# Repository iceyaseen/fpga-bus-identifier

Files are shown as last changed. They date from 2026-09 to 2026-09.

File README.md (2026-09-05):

# FPGA Communication Checker

A tool for figuring out how an unknown chip talks before you know anything about it. The usual situation: you have a small component with 3 or 4 pins, no datasheet, and no idea which protocol it speaks or what each pin does. Instead of guessing, you hook it up to this board and look at what actually happens on the lines.

## Status

The FPGA side is still in progress.

Working today:
- Edge capture on two probe channels, timestamped and streamed to a Python host over UART at 921600 baud.
- A framed, checksummed, self-resynchronising UART protocol between the FPGA and the host (start/stop/reset/status commands, edge records, ACK/ERROR replies).
- A from-scratch UART tx/rx pair, built and tested on the Tang Nano 9K.
- A 256-entry, block-RAM-backed capture FIFO, with high-water mark reported in the status reply.
- A PySide6 + pyqtgraph host GUI (dark instrument theme): live or offline (loaded from CSV) waveform view with pan/zoom/cursor/two draggable markers, a log-scale/zoomable pulse-width histogram, CSV export, and a "protocol hint" panel that reads the dominant pulse width and reports the closest matching clock/UART baud/1-Wire pulse - timing arithmetic only, not protocol decoding.
- An active I2C master: bidirectional open-drain probe drivers, software-switchable pull-ups, an electrical pre-scan (own pull-up / needs ours / held low / floating, per channel, before any bus traffic), and a 0x08-0x77 address sweep that reports every address that ACKs. Driven from the host's "Scan I2C" button; verified in simulation against a fake I2C slave (exactly one address found, START/STOP/ACK timing checked against spec) and confirmed on real hardware against an MLX90614 at 0x5A.

Not built yet:
- Reading actual data back from a found device (the I2C master currently only does the one-byte address-probe transaction a scan needs).
- Decoders for UART, 1-Wire, and PWM.
- Detection of analog (non-digital) devices - everything so far assumes the thing on the probes is digital.

## Host software

Requires Python 3 plus:
```
pip install PySide6 pyqtgraph pyserial
```
Then run:
```
python3 host/host.py [serial-port]
```
`host/protocol.py` holds the wire-format parser (framing, checksums, resync) and `host/hint.py` the protocol-hint arithmetic; both are plain Python with no GUI dependency, and each has a standalone test script (`host/test_frame_parser.py`, `host/test_hint.py`) that can be run without any hardware attached.

<p align="center">
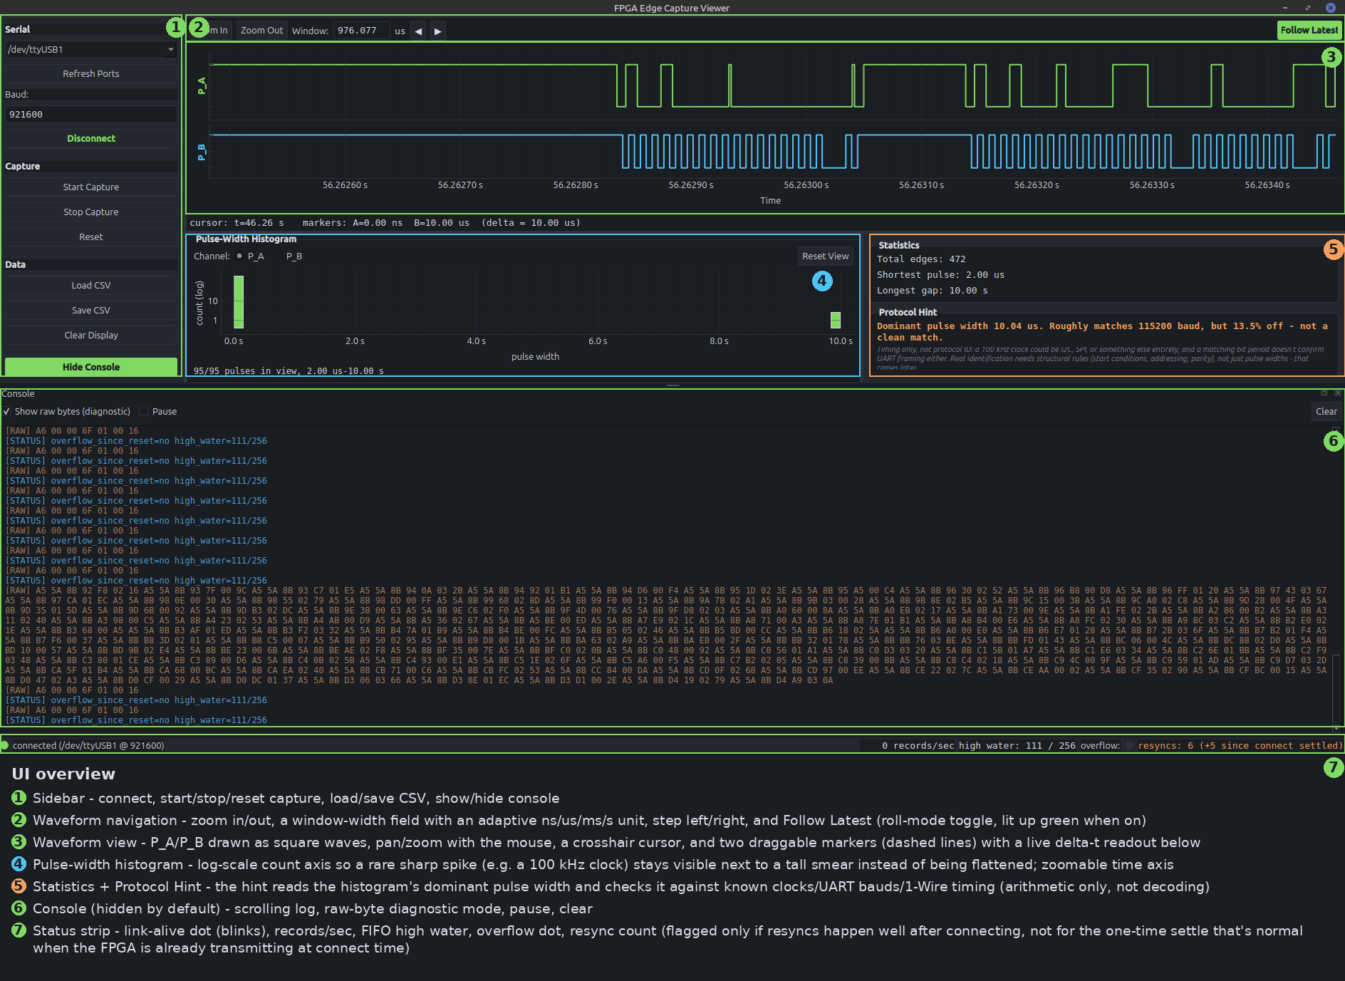
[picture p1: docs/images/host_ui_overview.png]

<br>
<sup>Screenshot of a real capture, probed on P_A/P_B. Numbered callouts below.</sup>
</p>

1. **Sidebar** - connect, start/stop/reset capture, load/save CSV, show/hide the console.
2. **Waveform navigation** - zoom in/out, a window-width field with an adaptive ns/us/ms/s unit, step left/right, and Follow Latest (an oscilloscope-style roll-mode toggle, lit up green when on).
3. **Waveform view** - P_A/P_B drawn as square waves. Pan/zoom with the mouse, a crosshair cursor that follows it, and two draggable markers (dashed lines) with a live delta-t readout below the plot.
4. **Pulse-width histogram** - log-scale count axis, so a rare sharp spike (e.g. a 100 kHz clock) stays visible next to a much taller structureless smear instead of being flattened to nothing; the time axis is independently zoomable to reveal fine structure.
5. **Statistics + Protocol Hint** - live edge/pulse/gap stats, plus a hint that reads the histogram's dominant pulse width and checks it against known clocks, standard UART bauds, and 1-Wire timing. Pure arithmetic, never a claim to have identified a protocol - see the disclaimer printed under it.
6. **Console** (hidden by default) - the scrolling log, a raw-byte diagnostic mode, pause (freezes the view without losing anything), and clear.
7. **Status strip** - a link-alive dot that blinks while connected, live records/sec, FIFO high-water mark, a sticky overflow-since-reset dot, and the frame resync count (flagged only if resyncs happen well after connecting, not for the one-time settle that's normal when the FPGA is already transmitting at connect time).

## The PCB

A shield that sits on top of the Tang Nano 9K. Built and working, not just designed - the photos below are the real board. It has two probe channels and a 4-pin socket for the device under test.
<p align="center">
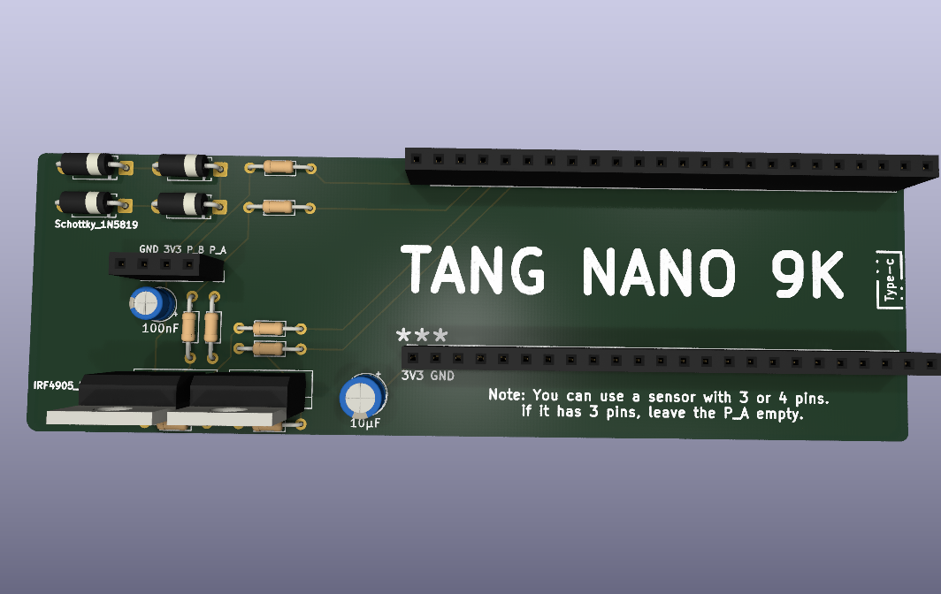
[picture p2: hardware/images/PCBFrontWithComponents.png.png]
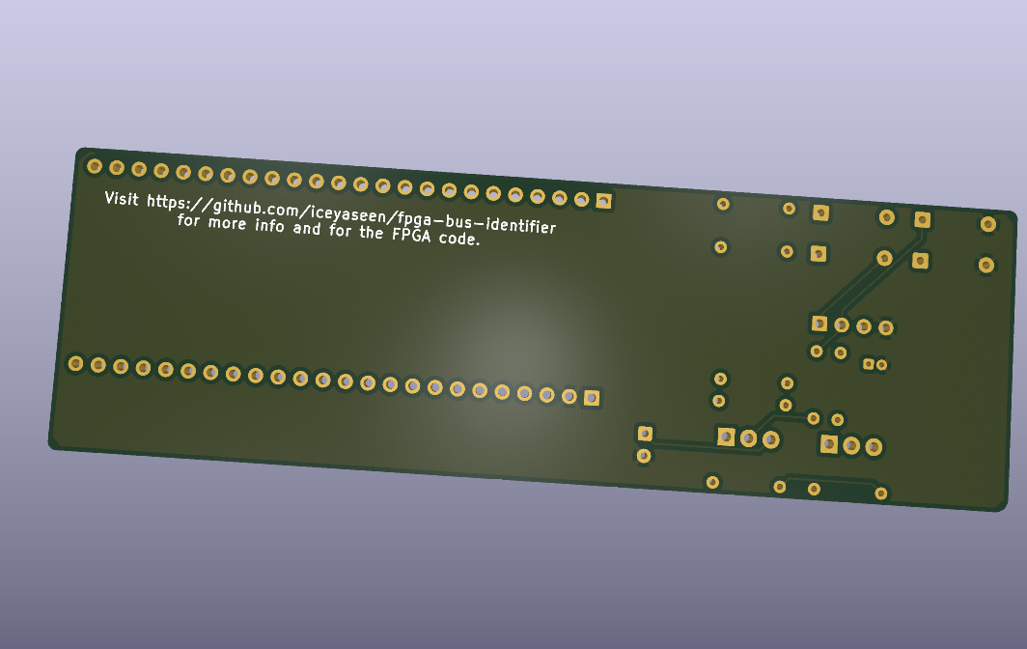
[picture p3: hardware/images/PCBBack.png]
  
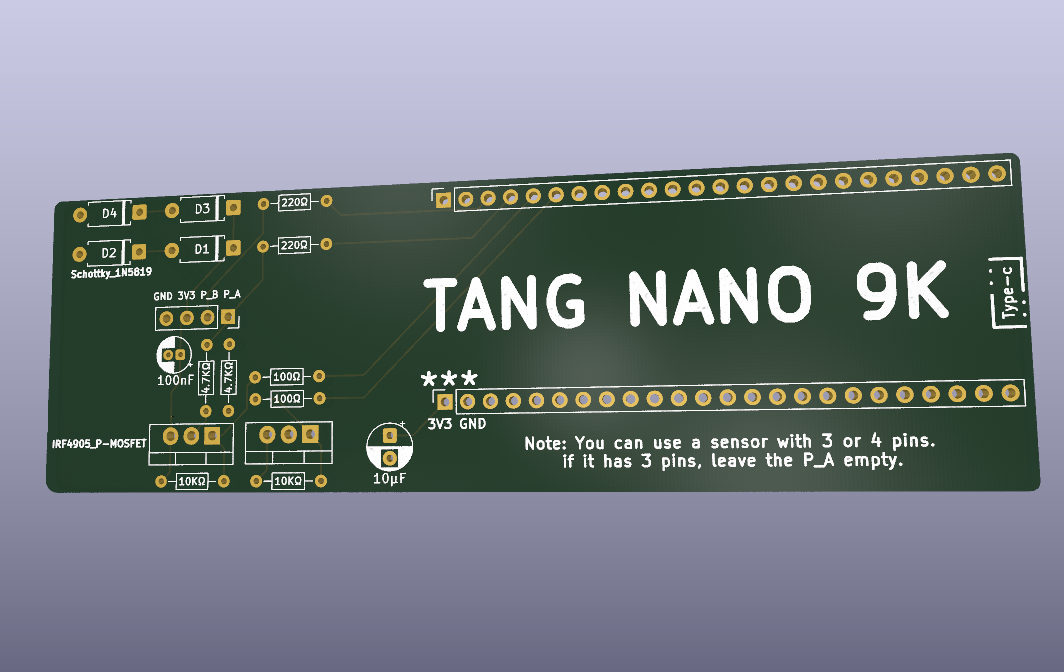
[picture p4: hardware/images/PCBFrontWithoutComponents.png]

<br>
Each part on the probe lines is there for a specific reason:
</p>

- **220 ohm series resistor** on each probe line. The tool is meant to connect to devices whose voltage and drive strength are unknown, so the series resistor limits current if something unexpected is being driven.
- **Schottky clamp diodes (1N5819)** to 3.3V and GND on each probe line, so an over-voltage device can't reach the FPGA pin directly. Schottky specifically, not an ordinary diode: an ordinary diode clamps around 4.0V, which is already too high for this FPGA's inputs.
- **4.7k pull-ups switched by P-channel MOSFETs.** This is the part that needs explaining: to find out whether an unknown device already has its own pull-up, you need to disconnect ours first and see what the line does on its own. A fixed pull-up would make that measurement impossible, so it's switchable instead.
- **10k gate-to-source resistors** on those MOSFETs, so they stay off during the few milliseconds after power-up while the FPGA is still loading its bitstream and its pins are floating.

## Pin assignments

| Tang Nano 9K pin | Signal | Notes |
|---|---|---|
| 54 | `ctrl_b` | Active low. Pulling low turns on channel B's pull-up MOSFET. |
| 55 | `ctrl_a` | Active low. Pulling low turns on channel A's pull-up MOSFET. |
| 56 | `probe_a`  | Probe channel A. |
| 57 | `probe_b`  | Probe channel B. |

Active low because these drive P-channel MOSFETs, which turn on when their gate is pulled low.

## Using it

Plug the unknown device into the 4-pin socket. A 4-pin device fills all four positions. A 3-pin device leaves `probe_a` empty.

## I2C scanning

Click **Scan I2C** in the host app. It runs two steps automatically:

1. **Electrical pre-scan** - before any bus traffic, each channel is classified purely by watching pull-up behaviour: *has its own pull-up* (reads high with ours off), *needs ours* (low/floating with ours off, clean high once ours switches on), *held low* (still low even with our pull-up on - a device driving it, or a short), or *floating* (unstable with no pull-up at all - nothing connected). This tells you whether the device is even I2C-shaped before wasting time on an address sweep.
2. **Address sweep** - START, address + write bit, check for ACK, STOP, for every address 0x08-0x77 (the valid 7-bit range). Every address that ACKs gets reported; an empty result is reported as "No devices found", not left ambiguous.

**Which probe is SDA and which is SCL is not auto-detected** - it's a host-side toggle ("SDA/SCL mapping: Normal (A=SDA, B=SCL) / Swapped (A=SCL, B=SDA)"), simpler and more transparent than guessing. If a scan against a known-good device finds nothing, flip the mapping and scan again. Verified against a real MLX90614 infrared thermometer (address 0x5A) on real hardware.

The scan's own generated I2C traffic is visible in the waveform view too (make sure capture is running - the "Scan I2C" button starts it automatically) - a good way to confirm the master is generating correct signals, not just trusting the reported result.

New host commands, single bytes like the existing ones (no framing needed on that side):

| Command | Effect |
|---|---|
| `A` / `a` | channel A pull-up on / off |
| `B` / `b` | channel B pull-up on / off |
| `N` / `W` | normal / swapped SDA-SCL pin mapping |
| `E` | run the electrical pre-scan |
| `I` | run the address sweep |

`E` and `I` are long-running, so unlike every other command their ACK is deferred until the operation actually finishes, not when the byte arrives - that's what lets the host safely chain pre-scan -> sweep off the pre-scan's own ACK. Two new frame types carry the results: `0xA9 PRESCAN_RESULT` (channel, category) and `0xAA ADDR_HIT` (one address that ACKed) - see `host/protocol.py` for the exact wire format, which follows the same `[MARKER][PAYLOAD][CHECKSUM]` scheme as everything else.

## Screenshots

<p align="center">
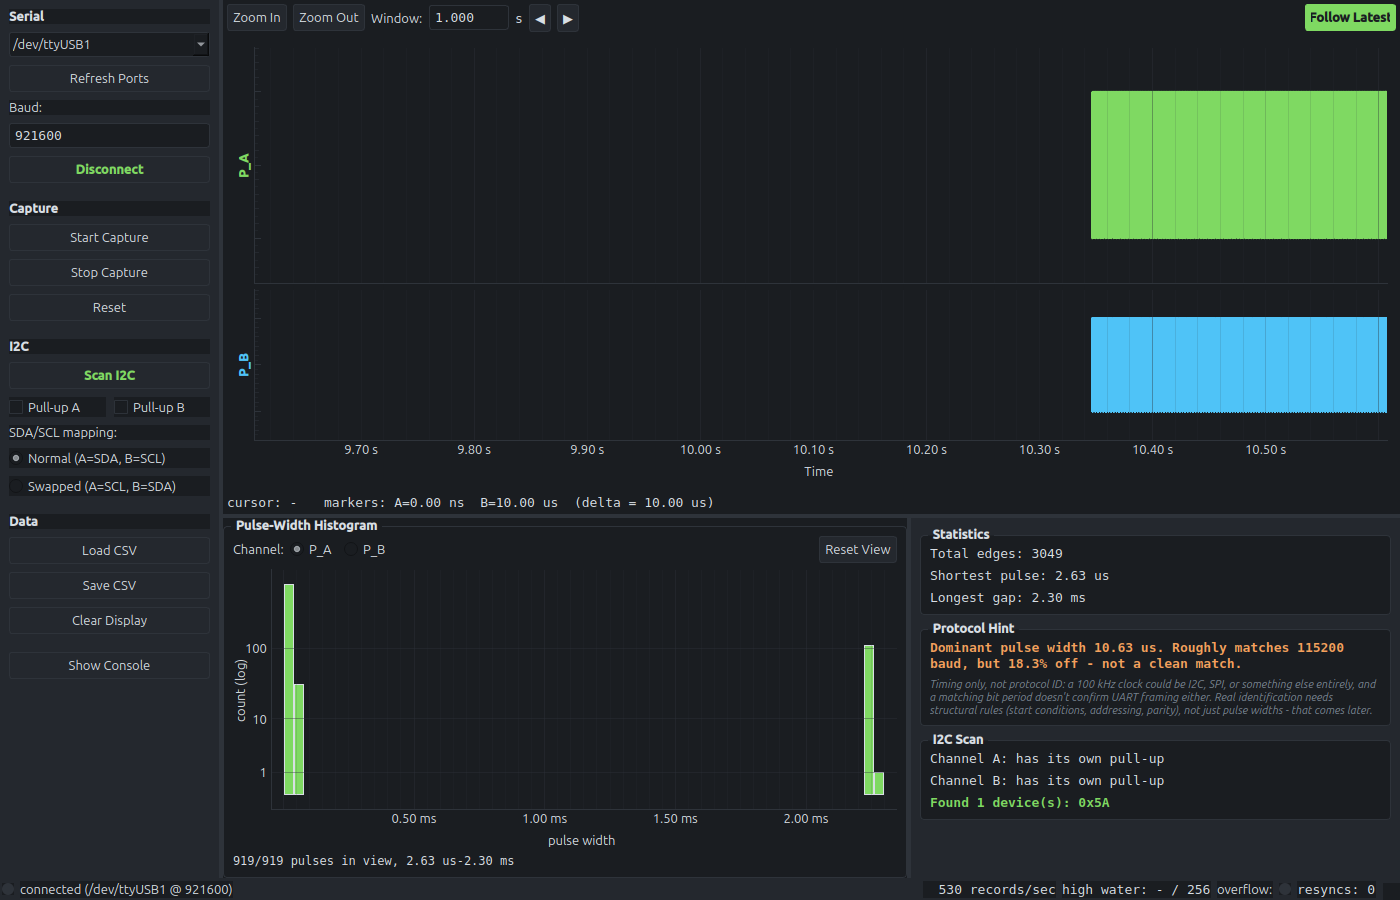
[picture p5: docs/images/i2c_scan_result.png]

<br>
<sup>A real scan: the pre-scan found a pull-up already present on both channels, and the address sweep found one device, at 0x5A - a real MLX90614 infrared thermometer.</sup>
</p>

<p align="center">
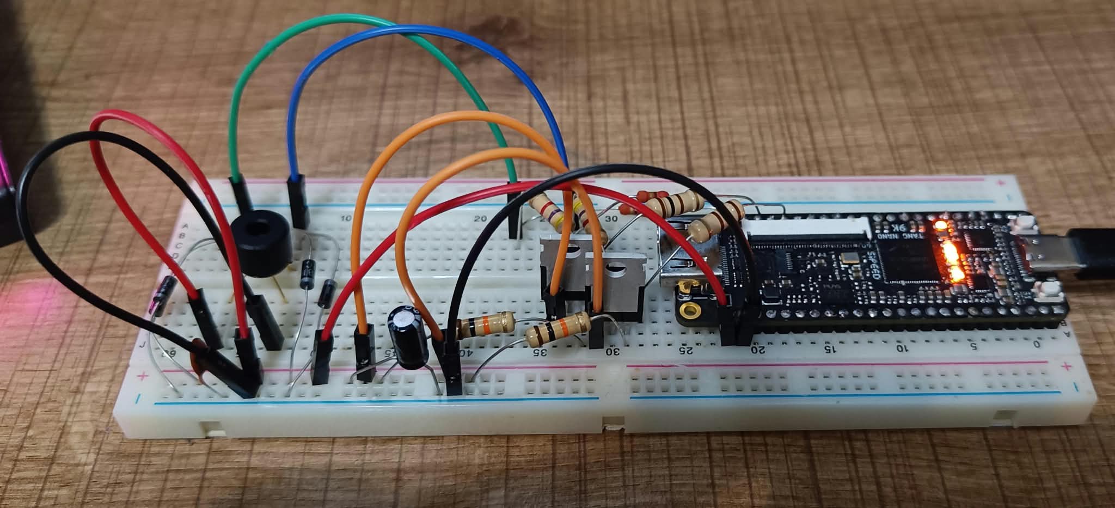
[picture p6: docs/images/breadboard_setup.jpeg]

<br>
<sup>The Tang Nano 9K wired up on a breadboard while testing against a real MLX90614.</sup>
</p>

General decoupling notes for this kind of breadboard setup: keep the 10uF bulk capacitor close to the 3.3V and GND rails it's decoupling, and keep the 100nF ceramic capacitor close to the sensor under test, not back at the FPGA end - it's there to filter noise right at the device, and a long lead defeats the point.

| Signal | Tang Nano 9K pin | Goes to |
|---|---|---|
| `probe_a` | 56 | Sensor SDA or SCL (depends on the SDA/SCL mapping setting) |
| `probe_b` | 57 | Sensor SCL or SDA (the other line) |
| `ctrl_a` | 55 | Channel A pull-up MOSFET gate |
| `ctrl_b` | 54 | Channel B pull-up MOSFET gate |
| 3.3V | - | Sensor VDD |
| GND | - | Sensor GND, common return |

Waveform and pulse-width-histogram screenshots of real captured I2C traffic, plus a contact-bounce histogram for comparison, are still to come - they need the hardware connected and, for the bounce case, a saved capture that doesn't exist yet.

## Known limitations

- Only single-ended protocols are in scope. CAN and RS-485 are differential and need a transceiver, so they're not supported.
- A completely unpowered unknown chip can't be identified from the outside. This tool only works on devices that respond when probed.
- There are two probe channels, so SPI (which needs more lines) isn't reachable yet.
- The protocol hint only measures timing. A 100 kHz clock could be I2C or SPI - the hint says "consistent with", it does not identify the protocol.

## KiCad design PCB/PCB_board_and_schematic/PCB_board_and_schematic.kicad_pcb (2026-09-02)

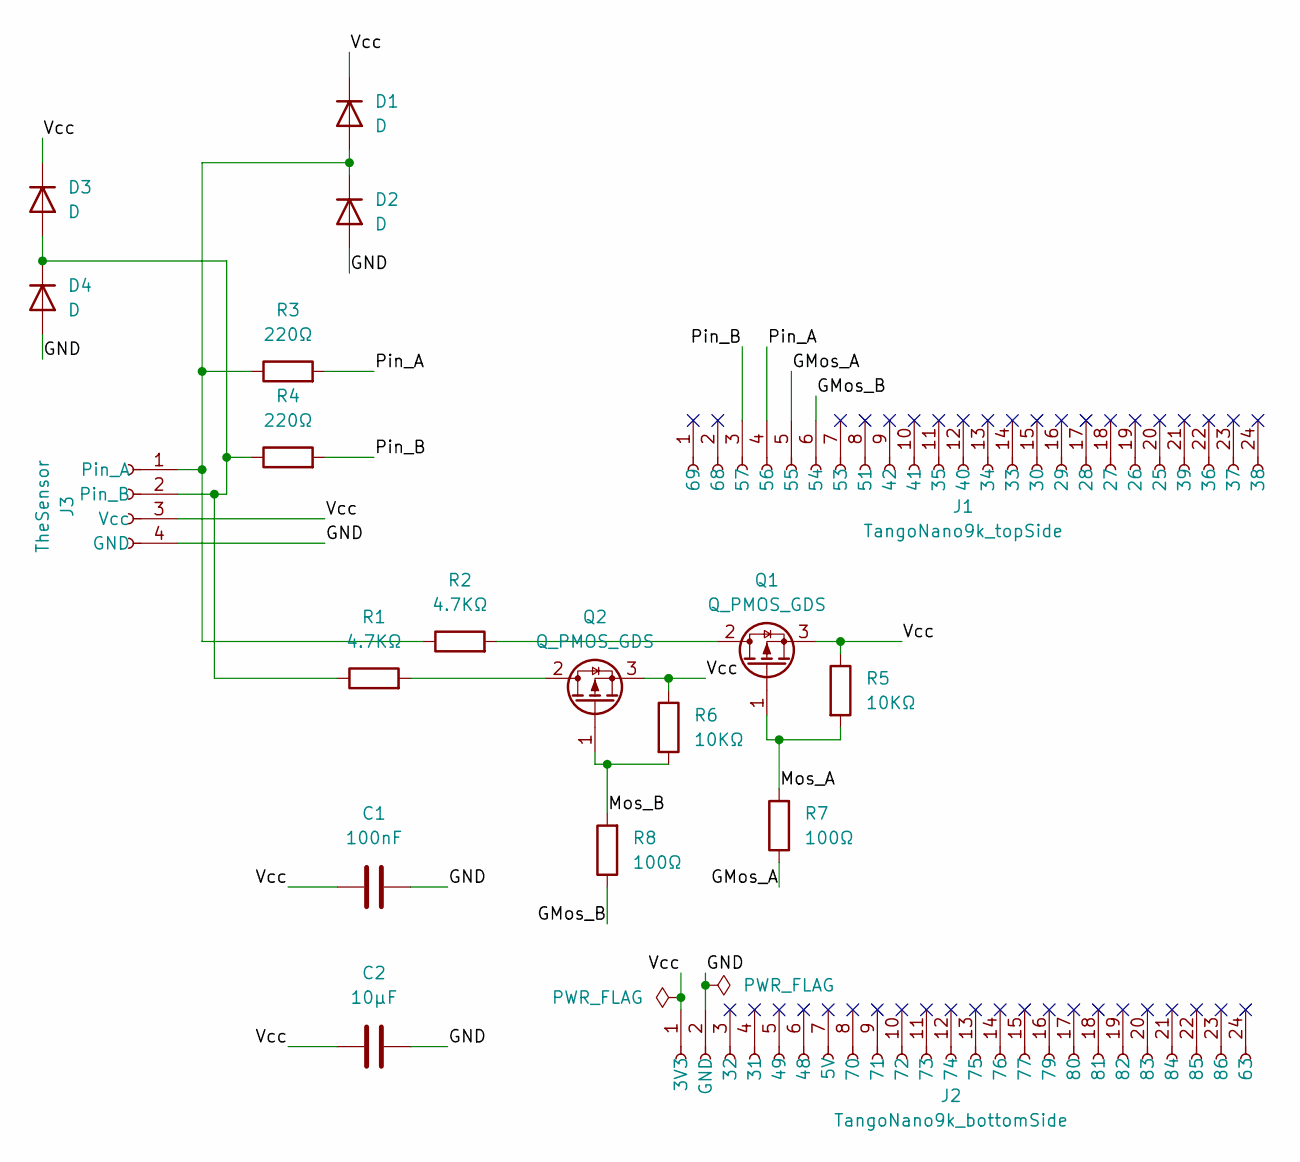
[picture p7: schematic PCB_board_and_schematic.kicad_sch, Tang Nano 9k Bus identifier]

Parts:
C1: 100nF; CP_Radial_D4.0mm_P1.50mm
C2: 10µF; CP_Radial_D5.0mm_P2.50mm
D1, D2, D3, D4: D; D_A-405_P7.62mm_Horizontal
J1: TangoNano9k_topSide; PinSocket_1x24_P2.54mm_Vertical
J2: TangoNano9k_bottomSide; PinSocket_1x24_P2.54mm_Vertical
J3: TheSensor; PinSocket_1x04_P2.54mm_Vertical
Q1, Q2: Q_PMOS_GDS; TO-220-3_Vertical
R1, R2: 4.7KΩ; R_Axial_DIN0204_L3.6mm_D1.6mm_P7.62mm_Horizontal
R3, R4: 220Ω; R_Axial_DIN0204_L3.6mm_D1.6mm_P7.62mm_Horizontal
R5, R6: 10KΩ; R_Axial_DIN0204_L3.6mm_D1.6mm_P7.62mm_Horizontal
R7, R8: 100Ω; R_Axial_DIN0204_L3.6mm_D1.6mm_P7.62mm_Horizontal

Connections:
/GMos_A: J1.5 (55), R7.1
/GMos_B: J1.6 (54), R8.1
/GND: C1.2, C2.2, D2.2 (A), D4.2 (A), J2.2 (GND), J3.4 (GND)
/Mos_A: Q1.1 (G), R5.2, R7.2
/Mos_B: Q2.1 (G), R6.2, R8.2
/Pin_A: J1.4 (56), R3.2
/Pin_B: J1.3 (57), R4.2
/Vcc: C1.1, C2.1, D1.1 (K), D3.1 (K), J2.1 (3V3), J3.3 (Vcc), Q1.3 (S), Q2.3 (S), R5.1, R6.1
unnamed: D1.2 (A), D2.1 (K), J3.1 (Pin_A), R2.1, R3.1
unnamed: D3.2 (A), D4.1 (K), J3.2 (Pin_B), R1.1, R4.1
unnamed: Q1.2 (D), R2.2
unnamed: Q2.2 (D), R1.2

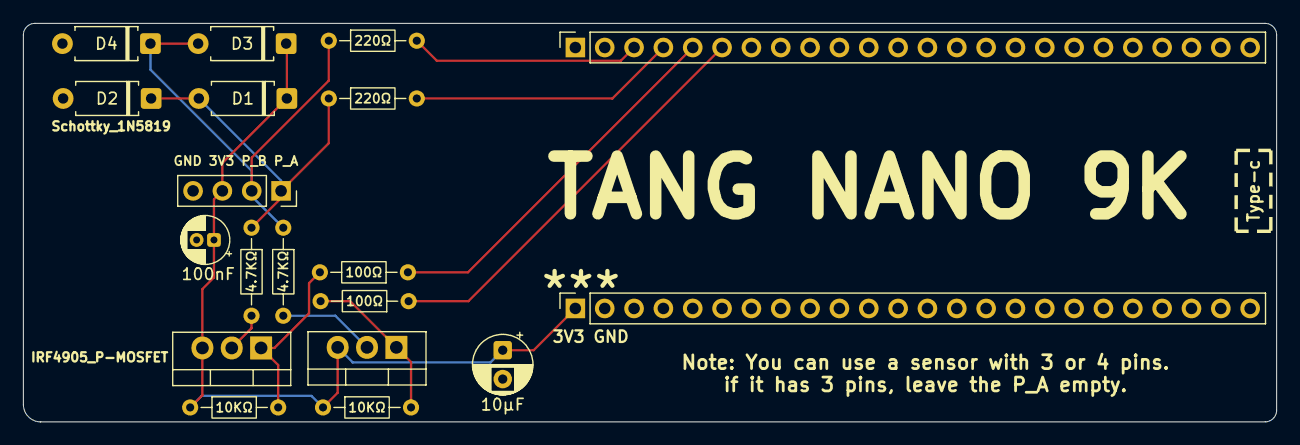
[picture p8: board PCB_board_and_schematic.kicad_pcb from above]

Board: 2 copper layers, 108.5 x 34.5 mm, 19 parts (0 on the bottom side), 12 nets.

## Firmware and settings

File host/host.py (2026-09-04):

#!/usr/bin/env python3
# ============================================================
#  GUI logic-analyser viewer for the Tang Nano 9K edge-capture engine.
#
#  PySide6 + pyqtgraph + pyserial. See protocol.py for the wire format
#  (framing/checksums/resync) - this file is UI only and never
#  reimplements that parsing.
#
#  Layout (see _build_ui):
#    +----------+----------------------------------------------+
#    | sidebar  |  waveform (P_A / P_B, pan+zoom, cursor,       |
#    | (connect,|   two draggable markers)                     |
#    |  start/  +---------------------+------------------------+
#    |  stop/   | pulse-width         | stats + protocol hint  |
#    |  reset,  | histogram           | panel                  |
#    |  csv)    | (log-scale count,   |                        |
#    |          |  zoomable time axis)|                        |
#    +----------+---------------------+------------------------+
#    | status strip: link dot, rate, high-water, overflow dot  |
#    +-----------------------------------------------------------+
#
#  Serial I/O lives entirely on a background thread (SerialReader)
#  that only ever reads bytes and pushes them onto a queue.Queue - it
#  never touches a Qt widget. A QTimer on the UI thread drains that
#  queue at a fixed ~20 Hz rate, feeds bytes to FrameParser, and only
#  then updates widgets - so a flood of records batches into one
#  redraw instead of one redraw per record.
#
#  Needs: pip install PySide6 pyqtgraph pyserial
# ============================================================
import sys
import os
import csv
import html
import math
import time
import threading
import queue

import numpy as np
from PySide6 import QtCore, QtGui, QtWidgets
import pyqtgraph as pg

import serial
import serial.tools.list_ports

sys.path.insert(0, os.path.dirname(os.path.abspath(__file__)))
from protocol import (
    NUM_CHANNELS, TICKS_PER_US, FIFO_DEPTH_DEFAULT,
    FrameParser, decode_edge, decode_stat, decode_ack, decode_err, ERR_CODE_NAMES,
    decode_prescan, decode_addrhit, PRESCAN_CATEGORY_NAMES,
)
from hint import hint_text, DISCLAIMER
from timefmt import format_duration_us, best_unit_for

# ---- dark instrument theme - exact palette from the spec ----
COLOR_BG = "#1A1D21"
COLOR_PANEL = "#24282E"
COLOR_GRID = "#2E333A"
COLOR_TEXT = "#D8DEE4"
COLOR_CH_A = "#7FD962"
COLOR_CH_B = "#4FC3F7"
COLOR_ACCENT = "#7FD962"
COLOR_WARN = "#F5A05C"
COLOR_ERROR = "#E06C75"
COLOR_MARKER = "#E06C75"   # not in the base 8, chosen so marker lines never
                           # visually blend with a channel trace or the grid
COLOR_MUTED_TEXT = "#7B8794"   # for de-emphasised text (the hint disclaimer) - COLOR_GRID
                                # is meant for plot gridlines and is nearly invisible as text
                                # against the similarly-dark COLOR_PANEL background

MONO_FONT_FAMILY = "DejaVu Sans Mono"

UI_HZ = 20
UI_PERIOD_MS = int(1000 / UI_HZ)     # batched redraw rate
STATS_PERIOD_MS = 500                # stats/histogram/hint recompute rate
BLINK_PERIOD_MS = 600                # "link alive" dot blink rate
STATUS_POLL_MS = 1000                # how often we send 'V' while connected
RESYNC_MIN_SETTLE_SECONDS = 0.2       # see _connect()/_tick(): minimum time before an empty
                                      # rx_queue counts as "caught up" rather than "reader
                                      # thread hasn't attempted its first read yet" - comfortably
                                      # more than that thread's own 50ms read timeout

WAVE_MAX_SAMPLES = 20000             # cap so redraw cost is bounded regardless of session length


def mono_font(size=10, bold=False):
    f = QtGui.QFont(MONO_FONT_FAMILY, size)
    f.setStyleHint(QtGui.QFont.Monospace)
    f.setBold(bold)
    return f


class TimeAxisItem(pg.AxisItem):
    """A time axis whose tick labels use the SAME ns/us/ms/s scheme as
    the cursor/marker/stats labels (format_duration_us / best_unit_for)
    instead of pyqtgraph's own SI-prefix system. That's not cosmetic:
    plotting already-converted microseconds with units="us" and letting
    pyqtgraph auto-prefix produces nonsense like "kus"/"Mus" (compounding
    an SI prefix onto a unit that's already one), and even with that
    disabled, pyqtgraph's own scaling would use different thresholds
    than our labels, so the axis and the readouts would disagree about
    what to call the same instant.

    The UNIT is picked from the values' own magnitude (so "~80s into
    the capture" stays visible even zoomed in tight), but the decimal
    PRECISION is picked from `spacing` - how far apart adjacent ticks
    actually are - not from the values themselves. Getting that wrong
    is exactly the failure mode this app needs to handle well: zoom in
    on a 5us burst that happens 80 REAL SECONDS into a capture, and
    every tick's absolute value rounds to the same "80.0 s" unless the
    precision comes from the (tiny) spacing instead.
    """
    def tickStrings(self, values, scale, spacing):
        if not values:
            return []
        ref = max((abs(v) for v in values), default=0.0)
        unit, unit_scale = best_unit_for(ref)
        spacing_in_unit = spacing / unit_scale
        decimals = 2
        if spacing_in_unit > 0:
            decimals = max(0, min(9, int(math.ceil(-math.log10(spacing_in_unit))) + 1))
        return [f"{v / unit_scale:.{decimals}f} {unit}" for v in values]


# ============================================================
#  Background thread: read raw bytes off the serial port, hand them
#  to the UI thread via a queue. Never touches a Qt widget - the UI
#  thread (MainWindow._tick) is the only thing allowed to do that.
# ============================================================
class SerialReader(threading.Thread):
    def __init__(self, ser, out_queue, stop_event):
        super().__init__(daemon=True)
        self.ser = ser
        self.out_queue = out_queue
        self.stop_event = stop_event

    def run(self):
        while not self.stop_event.is_set():
            try:
                chunk = self.ser.read(4096)
            except (serial.SerialException, OSError) as exc:
                self.out_queue.put(("error", str(exc)))
                return
            if chunk:
                self.out_queue.put(("data", chunk))


# ============================================================
#  Small "indicator light" widget: a filled circle whose colour is
#  set programmatically. Used for the link-alive dot (blinks while
#  connected) and the overflow dot (solid once overflow has latched).
# ============================================================
class Dot(QtWidgets.QLabel):
    def __init__(self, diameter=12, parent=None):
        super().__init__(parent)
        self.diameter = diameter
        self.setFixedSize(diameter, diameter)
        self._color = QtGui.QColor(COLOR_GRID)

    def set_color(self, hex_color):
        self._color = QtGui.QColor(hex_color)
        self.update()

    def paintEvent(self, event):
        painter = QtGui.QPainter(self)
        painter.setRenderHint(QtGui.QPainter.Antialiasing)
        painter.setBrush(QtGui.QBrush(self._color))
        painter.setPen(QtCore.Qt.NoPen)
        painter.drawEllipse(0, 0, self.diameter, self.diameter)


# ============================================================
#  Main window
# ============================================================
class MainWindow(QtWidgets.QMainWindow):
    def __init__(self, initial_port=None):
        super().__init__()
        self.setWindowTitle("FPGA Edge Capture Viewer")
        self.resize(1400, 900)

        # ---- connection state ----
        self.ser = None
        self.reader_thread = None
        self.stop_event = None
        self.rx_queue = queue.Queue()
        self.parser = FrameParser()
        self.connected = False
        self.raw_mode = False

        # ---- capture state / unified record store (live or loaded CSV) ----
        self.prev_ts = None
        self.records = []          # (ts_ticks, state) - unbounded, source of truth for CSV save + stats
        self.wave_records = []     # capped view of self.records, for waveform redraw cost
        self.recv_times = []       # wall-clock arrival times (monotonic), for records/sec
        self.records_received = 0
        self.last_record_wall_time = None
        self.overflow_since_reset = False
        self.fifo_high_water = 0
        self.fifo_depth = FIFO_DEPTH_DEFAULT

        # ---- I2C scan state (Part B4) ----
        self.prescan_results = {}   # channel (0/1) -> category code
        self.found_addresses = []   # 7-bit addresses that ACKed, in scan order
        self.i2c_scan_stage = None  # None idle; 'prescan' waiting for E's ack; 'sweep' waiting for I's ack

        # ---- stats / histogram state ----
        self.stats_dirty = True
        self.pulse_widths = {ch: [] for ch in range(NUM_CHANNELS)}
        self.shortest_pulse_us = None
        self.longest_gap_us = None
        self.hist_channel = 0
        self.hist_view_min = None   # None = auto (full range of selected channel)
        self.hist_view_max = None
        self._hist_redraw_in_progress = False   # guards against our own setXRange() re-triggering the handler below

        # ---- resync-vs-startup bookkeeping (see _connect()/_tick()) ----
        self._resync_baseline = None

        # ---- waveform navigation state ----
        self.follow_latest = True       # oscilloscope "roll mode": view tracks the newest data
        self._wave_program_range_change = False   # guards our own setXRange() calls, same idea as the histogram's

        # ---- console panel state ----
        self._log_paused = False
        self._log_buffer = []   # (text, color) queued while paused - nothing is lost, just not shown yet

        self._build_ui()
        self._refresh_ports(preselect=initial_port)
        self._set_controls_enabled(False)

        self.ui_timer = QtCore.QTimer(self)
        self.ui_timer.timeout.connect(self._tick)
        self.ui_timer.start(UI_PERIOD_MS)

        self.stats_timer = QtCore.QTimer(self)
        self.stats_timer.timeout.connect(self._stats_tick)
        self.stats_timer.start(STATS_PERIOD_MS)

        self.blink_timer = QtCore.QTimer(self)
        self.blink_timer.timeout.connect(self._blink_tick)
        self.blink_timer.start(BLINK_PERIOD_MS)
        self._blink_on = False

        self.status_poll_timer = QtCore.QTimer(self)
        self.status_poll_timer.timeout.connect(self._cmd_status)

    # ========================================================
    #  UI construction
    # ========================================================
    def _build_ui(self):
        self.setStyleSheet(f"""
            QMainWindow, QWidget {{ background: {COLOR_BG}; color: {COLOR_TEXT}; }}
            #Sidebar, #StatsPanel {{ background: {COLOR_PANEL}; }}
            QPushButton {{
                background: {COLOR_PANEL}; color: {COLOR_TEXT};
                border: 1px solid {COLOR_GRID}; border-radius: 3px; padding: 5px;
            }}
            QPushButton:hover {{ border-color: {COLOR_ACCENT}; }}
            QPushButton:disabled {{ color: {COLOR_GRID}; }}
            QPushButton#Accent {{ color: {COLOR_ACCENT}; font-weight: bold; }}
            QPushButton:checked {{
                background: {COLOR_ACCENT}; color: {COLOR_BG};
                font-weight: bold; border-color: {COLOR_ACCENT};
            }}
            QLineEdit, QComboBox {{
                background: {COLOR_BG}; color: {COLOR_TEXT};
                border: 1px solid {COLOR_GRID}; border-radius: 3px; padding: 3px;
            }}
            QCheckBox, QLabel, QRadioButton {{ color: {COLOR_TEXT}; }}
            QGroupBox {{
                border: 1px solid {COLOR_GRID}; border-radius: 4px; margin-top: 8px;
                color: {COLOR_TEXT}; font-weight: bold;
            }}
            QGroupBox::title {{ subcontrol-origin: margin; left: 8px; padding: 0 3px; }}
            QSplitter::handle {{ background: {COLOR_GRID}; }}
            QStatusBar {{ background: {COLOR_PANEL}; }}
            QPlainTextEdit {{ background: {COLOR_BG}; color: {COLOR_TEXT}; }}
        """)

        main_splitter = QtWidgets.QSplitter(QtCore.Qt.Horizontal)
        self.setCentralWidget(main_splitter)

        main_splitter.addWidget(self._build_sidebar())

        right = QtWidgets.QSplitter(QtCore.Qt.Vertical)
        right.addWidget(self._build_waveform_panel())

        bottom = QtWidgets.QSplitter(QtCore.Qt.Horizontal)
        bottom.addWidget(self._build_histogram_panel())
        bottom.addWidget(self._build_stats_hint_panel())
        bottom.setSizes([700, 500])
        right.addWidget(bottom)
        right.setSizes([500, 350])

        main_splitter.addWidget(right)
        main_splitter.setSizes([220, 1180])

        self._build_status_strip()
        self._build_log_dock()

    def _build_sidebar(self):
        panel = QtWidgets.QWidget()
        panel.setObjectName("Sidebar")
        panel.setMinimumWidth(200)
        panel.setMaximumWidth(260)
        lay = QtWidgets.QVBoxLayout(panel)
        lay.setSpacing(8)

        lay.addWidget(QtWidgets.QLabel("<b>Serial</b>"))
        self.port_combo = QtWidgets.QComboBox()
        lay.addWidget(self.port_combo)
        refresh_btn = QtWidgets.QPushButton("Refresh Ports")
        refresh_btn.clicked.connect(lambda: self._refresh_ports())
        lay.addWidget(refresh_btn)

        lay.addWidget(QtWidgets.QLabel("Baud:"))
        self.baud_edit = QtWidgets.QLineEdit("921600")
        self.baud_edit.setFont(mono_font())
        lay.addWidget(self.baud_edit)

        self.connect_btn = QtWidgets.QPushButton("Connect")
        self.connect_btn.setObjectName("Accent")
        self.connect_btn.clicked.connect(self._toggle_connect)
        lay.addWidget(self.connect_btn)

        lay.addSpacing(10)
        lay.addWidget(QtWidgets.QLabel("<b>Capture</b>"))
        self.start_btn = QtWidgets.QPushButton("Start Capture")
        self.start_btn.clicked.connect(self._cmd_start)
        lay.addWidget(self.start_btn)
        self.stop_btn = QtWidgets.QPushButton("Stop Capture")
        self.stop_btn.clicked.connect(self._cmd_stop)
        lay.addWidget(self.stop_btn)
        self.reset_btn = QtWidgets.QPushButton("Reset")
        self.reset_btn.clicked.connect(self._cmd_reset)
        lay.addWidget(self.reset_btn)

        lay.addSpacing(10)
        lay.addWidget(QtWidgets.QLabel("<b>I2C</b>"))
        self.scan_i2c_btn = QtWidgets.QPushButton("Scan I2C")
        self.scan_i2c_btn.setObjectName("Accent")
        self.scan_i2c_btn.setToolTip("Runs the electrical pre-scan, then sweeps addresses 0x08-0x77")
        self.scan_i2c_btn.clicked.connect(self._cmd_scan_i2c)
        lay.addWidget(self.scan_i2c_btn)

        pu_row = QtWidgets.QHBoxLayout()
        self.pullup_a_check = QtWidgets.QCheckBox("Pull-up A")
        self.pullup_a_check.toggled.connect(self._on_pullup_a_toggled)
        pu_row.addWidget(self.pullup_a_check)
        self.pullup_b_check = QtWidgets.QCheckBox("Pull-up B")
        self.pullup_b_check.toggled.connect(self._on_pullup_b_toggled)
        pu_row.addWidget(self.pullup_b_check)
        lay.addLayout(pu_row)

        # which physical probe channel is SDA vs SCL isn't auto-detected
        # (see i2c_scanner section of the README for why) - if a scan
        # comes back empty, try the other mapping and scan again
        lay.addWidget(QtWidgets.QLabel("SDA/SCL mapping:"))
        self.pin_map_group = QtWidgets.QButtonGroup(panel)
        self.pin_map_normal_radio = QtWidgets.QRadioButton("Normal (A=SDA, B=SCL)")
        self.pin_map_normal_radio.setChecked(True)
        self.pin_map_swapped_radio = QtWidgets.QRadioButton("Swapped (A=SCL, B=SDA)")
        self.pin_map_group.addButton(self.pin_map_normal_radio, 0)
        self.pin_map_group.addButton(self.pin_map_swapped_radio, 1)
        self.pin_map_normal_radio.toggled.connect(self._on_pin_map_changed)
        lay.addWidget(self.pin_map_normal_radio)
        lay.addWidget(self.pin_map_swapped_radio)

        lay.addSpacing(10)
        lay.addWidget(QtWidgets.QLabel("<b>Data</b>"))
        self.load_csv_btn = QtWidgets.QPushButton("Load CSV")
        self.load_csv_btn.clicked.connect(self._load_csv)
        lay.addWidget(self.load_csv_btn)
        self.save_csv_btn = QtWidgets.QPushButton("Save CSV")
        self.save_csv_btn.clicked.connect(self._save_csv)
        lay.addWidget(self.save_csv_btn)
        clear_btn = QtWidgets.QPushButton("Clear Display")
        clear_btn.clicked.connect(self._clear_display)
        lay.addWidget(clear_btn)

        lay.addSpacing(10)
        self.console_toggle_btn = QtWidgets.QPushButton("Show Console")
        self.console_toggle_btn.setCheckable(True)
        self.console_toggle_btn.toggled.connect(self._on_console_toggle_clicked)
        lay.addWidget(self.console_toggle_btn)

        lay.addStretch(1)
        return panel

    def _build_waveform_panel(self):
        container = QtWidgets.QWidget()
        v = QtWidgets.QVBoxLayout(container)
        v.setContentsMargins(4, 4, 4, 4)

        v.addLayout(self._build_wave_nav_toolbar())

        self.wave_widget = pg.GraphicsLayoutWidget()
        v.addWidget(self.wave_widget, stretch=1)

        self.plot_a = self.wave_widget.addPlot(row=0, col=0)
        self.wave_widget.nextRow()
        self.plot_b = self.wave_widget.addPlot(row=1, col=0, axisItems={"bottom": TimeAxisItem(orientation="bottom")})

        for p, color, name in ((self.plot_a, COLOR_CH_A, "P_A"), (self.plot_b, COLOR_CH_B, "P_B")):
            p.showGrid(x=True, y=False, alpha=0.4)
            p.setYRange(-0.3, 1.3, padding=0)
            p.getAxis("left").setStyle(showValues=False)
            p.getAxis("left").setPen(pg.mkPen(COLOR_GRID))
            p.getAxis("bottom").setPen(pg.mkPen(COLOR_GRID))
            p.setLabel("left", name, color=color, **{"font-weight": "bold"})
            p.getViewBox().setMouseEnabled(x=True, y=False)
            p.setMenuEnabled(False)
            p.hideButtons()   # pyqtgraph's default "A" auto-range corner button - it bypasses
                               # our own view-management (follow_latest, guarded range changes)

        self.plot_a.getAxis("bottom").setStyle(showValues=False)
        self.plot_b.setLabel("bottom", "Time", color=COLOR_TEXT)
        self.plot_b.setXLink(self.plot_a)
        # this is the ONLY x-range change hook we need: plot_b is linked to
        # plot_a, so any range change on either shows up here once
        self.plot_a.getViewBox().sigXRangeChanged.connect(self._on_wave_range_changed)

        self.curve_a = self.plot_a.plot(pen=pg.mkPen(COLOR_CH_A, width=2))
        self.curve_b = self.plot_b.plot(pen=pg.mkPen(COLOR_CH_B, width=2))

        # non-interactive crosshair that follows the mouse (one line per
        # plot, kept at the same x so it visually spans both channels)
        cursor_pen = pg.mkPen(COLOR_TEXT, width=1, style=QtCore.Qt.DashLine)
        self.cursor_line_a = pg.InfiniteLine(angle=90, movable=False, pen=cursor_pen)
        self.cursor_line_b = pg.InfiniteLine(angle=90, movable=False, pen=cursor_pen)
        self.plot_a.addItem(self.cursor_line_a)
        self.plot_b.addItem(self.cursor_line_b)

        # two draggable markers for manual delta-t measurement (e.g. a bit
        # period). Each marker is really TWO InfiniteLine instances (one per
        # stacked plot) kept in sync programmatically so the line visually
        # spans both channel rows even though they're separate PlotItems.
        marker_pen = pg.mkPen(COLOR_MARKER, width=1, style=QtCore.Qt.DashLine)
        self.marker1_a = pg.InfiniteLine(angle=90, movable=True, pen=marker_pen)
        self.marker1_b = pg.InfiniteLine(angle=90, movable=True, pen=marker_pen)
        self.marker2_a = pg.InfiniteLine(angle=90, movable=True, pen=marker_pen)
        self.marker2_b = pg.InfiniteLine(angle=90, movable=True, pen=marker_pen)
        for m, pos in ((self.marker1_a, 0), (self.marker1_b, 0), (self.marker2_a, 10), (self.marker2_b, 10)):
            m.setPos(pos)
        self.plot_a.addItem(self.marker1_a)
        self.plot_b.addItem(self.marker1_b)
        self.plot_a.addItem(self.marker2_a)
        self.plot_b.addItem(self.marker2_b)
        self._link_markers(self.marker1_a, self.marker1_b)
        self._link_markers(self.marker2_a, self.marker2_b)

        self.wave_widget.scene().sigMouseMoved.connect(self._on_wave_mouse_moved)

        readout = QtWidgets.QHBoxLayout()
        self.cursor_label = QtWidgets.QLabel("cursor: -")
        self.cursor_label.setFont(mono_font())
        readout.addWidget(self.cursor_label)
        readout.addSpacing(20)
        self.marker_label = QtWidgets.QLabel()
        self.marker_label.setFont(mono_font())
        readout.addWidget(self.marker_label)
        readout.addStretch(1)
        v.addLayout(readout)
        self._update_marker_readout()   # fill in the initial text using real formatting

        # a deliberate default window width, rather than leaving it to
        # whatever pyqtgraph's own auto-fit-to-data happens to land on
        # before any real navigation action - this also disables that
        # auto-fit immediately (setXRange does that as a side effect),
        # which follow_latest's own scrolling depends on from this
        # point on: it always adjusts an existing explicit range, never
        # lets the ViewBox silently auto-fit underneath it
        self._set_wave_xrange(0.0, 1_000_000.0)   # 1 second, arbitrary position
        self._update_wave_width_field(1_000_000.0)

        return container
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

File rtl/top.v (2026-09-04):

// ============================================================
//  top.v - FPGA communication checker
//  Board: Sipeed Tang Nano 9K (27 MHz clock)
//
//  Captures edges on two probe channels (probe_a/probe_b), timestamps
//  them against a free-running counter, and streams them to a host PC
//  over UART as framed, checksummed records. Also drives probe_a/
//  probe_b as an I2C master to scan for devices (Part B4) - see
//  i2c_master.v/i2c_prescan.v/i2c_scanner.v. See host.py for the
//  matching wire protocol and tangnano9k.cst for the pin mapping.
//
//  File layout follows strict declare-before-use order throughout:
//  Icarus's default elaboration mode rejects forward references (an
//  identifier used in an expression or port connection before any
//  `reg`/`wire` declaration of it has appeared earlier in the file),
//  so every block below is ordered so nothing it references was
//  declared later. Where two things are genuinely interdependent
//  (e.g. the TX arbiter's own state needs to exist before the I2C
//  submodules that report_ack/hit_ack feed back into it), the
//  declaration is pulled up near the top and the actual driving
//  logic stays lower down, next to the states it walks through.
// ============================================================

module top #(
    parameter NUM_CHANNELS  = 2,        // probe channel count - see the probe_driver instances below
    parameter FIFO_DEPTH    = 256,      // must be a power of 2 - see fifo.v; BRAM-backed at this depth
    // I2C address sweep range - real hardware always gets the full valid
    // 7-bit range (default); a testbench can narrow this for a fast,
    // still fully representative simulation. See i2c_scanner.v.
    parameter [7:0] I2C_ADDR_FIRST = 8'h08,
    parameter [7:0] I2C_ADDR_LAST  = 8'h77
) (
    input  wire       clk,        // 27 MHz, pin 52

    input  wire        btn1,       // active low, pin 3
    input  wire        btn2,       // active low, pin 4

    input  wire       uart_rx,    // from host (USB-serial TXD), pin 18
    output wire       uart_tx,    // to host (USB-serial RXD), pin 17

    output wire        ctrl_a,     // P-MOSFET gate, channel A pull-up - active low, pin 55
    output wire        ctrl_b,     // P-MOSFET gate, channel B pull-up - active low, pin 54

    output wire [5:0] led,

    inout  wire        probe_a,    // logic-analyser probe, channel A - pin 56
    inout  wire        probe_b     // logic-analyser probe, channel B - pin 57
);

    // ---- buttons: debounce + rising-edge detect --------------
    // Not consumed by anything yet (the display logic that used to read
    // these has been removed) - kept wired up for a future feature.
    wire b1_clean, b2_clean;

    debounce d1 (.clk(clk), .noisy(~btn1), .clean(b1_clean));
    debounce d2 (.clk(clk), .noisy(~btn2), .clean(b2_clean));

    reg b1_prev = 1'b0;
    reg b2_prev = 1'b0;
    wire b1_edge = b1_clean & ~b1_prev;
    wire b2_edge = b2_clean & ~b2_prev;

    always @(posedge clk) begin
        b1_prev <= b1_clean;
        b2_prev <= b2_clean;
    end

    // ---- UART: framed protocol only - no housekeeping text, no byte
    //      echo. Commands get a real ACK/ERROR/status reply instead ----
    wire       uart_tx_busy;
    reg        uart_tx_start = 1'b0;
    reg  [7:0] uart_tx_data  = 8'h00;
    wire [7:0] uart_rx_data;
    wire       uart_rx_valid;

    uart_tx tx_unit (
        .clk   (clk),
        .start (uart_tx_start),
        .data  (uart_tx_data),
        .tx    (uart_tx),
        .busy  (uart_tx_busy)
    );

    uart_rx rx_unit (
        .clk   (clk),
        .rx    (uart_rx),
        .data  (uart_rx_data),
        .valid (uart_rx_valid)
    );

    // low 6 bits of the last byte received, shown on the LEDs
    reg [7:0] rx_byte_latch = 8'h00;
    always @(posedge clk) begin
        if (uart_rx_valid) rx_byte_latch <= uart_rx_data;
    end

    // ---- TX arbiter state names + the regs it owns, declared up here
    // (ahead of everything below that needs to reference tx_state, or
    // needs report_ack/hit_ack, which are themselves computed from
    // tx_state) so every reference in this file is to an already-
    // declared symbol. The arbiter's actual always block (the logic
    // that drives uart_tx_data/tx_state) still lives much further
    // down, where it reads naturally alongside the states it walks
    // through and the *_pending flags it arbitrates between.
    //
    // 13 states now (IDLE + 2 each for REC/STAT/ACK/ERR/PRESCAN/ADDRHIT)
    // need 4 bits.
    localparam TX_IDLE          = 4'd0,
               TX_REC            = 4'd1,
               TX_REC_WAIT       = 4'd2,
               TX_STAT           = 4'd3,
               TX_STAT_WAIT      = 4'd4,
               TX_ACK            = 4'd5,
               TX_ACK_WAIT       = 4'd6,
               TX_ERR            = 4'd7,
               TX_ERR_WAIT       = 4'd8,
               TX_PRESCAN        = 4'd9,
               TX_PRESCAN_WAIT   = 4'd10,
               TX_ADDRHIT        = 4'd11,
               TX_ADDRHIT_WAIT   = 4'd12;

    reg [3:0] tx_state          = TX_IDLE;
    reg [2:0] rec_byte_idx      = 3'd0;   // EDGE_RECORD is 7 bytes: idx 0..6
    reg [2:0] stat_byte_idx     = 3'd0;   // STATUS_REPLY is 7 bytes: idx 0..6
    reg [1:0] ack_byte_idx      = 2'd0;   // ACK is 3 bytes: idx 0..2
    reg [1:0] err_byte_idx      = 2'd0;   // ERROR is 4 bytes: idx 0..3
    reg [1:0] prescan_byte_idx  = 2'd0;   // PRESCAN_RESULT is 4 bytes: idx 0..3
    reg [1:0] addrhit_byte_idx  = 2'd0;   // ADDR_HIT is 3 bytes: idx 0..2

    // combinational, computed straight from the TX arbiter's own state
    // (same pattern as rec_tx_done further down): the SOLE way
    // i2c_prescan/i2c_scanner learn "your frame was fully sent, go
    // ahead and clear your own pending flag" - top.v never touches
    // report_pending/hit_pending directly, for the same reason
    // rec_pending has exactly one driver (see the popper's comment).
    wire report_ack = (tx_state == TX_PRESCAN_WAIT) && !uart_tx_busy && (prescan_byte_idx == 2'd3);
    wire hit_ack    = (tx_state == TX_ADDRHIT_WAIT) && !uart_tx_busy && (addrhit_byte_idx == 2'd2);
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

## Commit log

2026-08-30 First commit, testing the FPGA board if it is working properly
2026-08-30 More testing to check built in buttons
2026-08-31 Tested comunication between fpga board and the labtop
2026-09-01 Added pcb design folder.
    [PCB_board_and_schematic.kicad_pcb, PCB_board_and_schematic.kicad_sch]
2026-09-01 Added the needed components to the schematic design.
    [PCB_board_and_schematic.kicad_sch]
2026-09-01 Changed some components in the schematic design (added diodes and deleted BAT54S)
    [PCB_board_and_schematic.kicad_sch]
2026-09-01 wired schematic design (except FPGA pins, not selected for now).
    [PCB_board_and_schematic.kicad_sch]
2026-09-02 Fixed PCB schematic (mosfet placement) and finished the full PCB design (except the Pin_a, Pin_b, and the mosfets gates because not selected yet)
    [PCB_board_and_schematic.kicad_pcb, PCB_board_and_schematic.kicad_sch]
2026-09-02 finished PCB design completly.
    [PCB_board_and_schematic.kicad_pcb, PCB_board_and_schematic.kicad_sch]
2026-09-02 Added images of the PCB design.
    [PCB_board_and_schematic.kicad_pcb]
2026-09-04 Updated pins connections and tested host.py by reciving I2C data
2026-09-04 the host.py can now identify in which adress a I2C device is located.
